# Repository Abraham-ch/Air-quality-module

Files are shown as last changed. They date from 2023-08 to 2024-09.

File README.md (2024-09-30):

# Documentation
## Introduction
To develop a smart city, good air quality is essential, as it is fundamental for the health and well-being of citizens. High levels of air pollution can have negative effects on health, such as respiratory problems, cardiovascular diseases, cancer, and other chronic conditions. The Breath proposal was designed to take measures to reduce air pollution and improve the quality of life for citizens by promoting the use of renewable energy, and encouraging public transportation and sustainable mobility.
## Description
Breath is a project dedicated to air quality monitoring. It consists of an IoT device that contains sensors such as PMS, BME280, and SCD40, capable of measuring humidity, temperature, PM10 and PM2.5 particle concentrations, and various gases that, at high concentrations, could be harmful to humans or cause irritation and respiratory difficulties. The project was developed to be scalable and compact. Due to its low cost, this device can be deployed in various settings, covering crowded places, industrial facilities, and indoor environments. It only requires a power source and WiFi, making it portable if needed. Once deployed, the data will be displayed on an LCD screen or, if required, virtually, showing concentrations through graphs and storing data in the cloud for later use, such as research, monitoring, and forecasting.

## Breath Device
The project's goal is to provide real-time information on air quality. This need arose due to the significant pollution gap in Peru, along with the poor awareness of this issue in Lima.

### Technology Selection
For the project, we will include sensors in addition to a microcontroller and an LCD screen.

<!-- TABLES -->

<table class="tg">
<thead>
  <tr>
    <th class="tg-0pky"></th>
    <th class="tg-9wq8">Module</th>
    <th class="tg-9wq8">Input Voltage</th>
    <th class="tg-9wq8">Output Voltage</th>
  </tr>
</thead>
<tbody>
  <tr>
    <td class="tg-0pky">ESP32 DevKit V1</td>
    <td class="tg-9wq8">Esp32</td>
    <td class="tg-9wq8">5.5 V</td>
    <td class="tg-9wq8">3.3 V</td>
  </tr>
  <tr>
    <td class="tg-0pky">TFT</td>
    <td class="tg-9wq8">TFT 4" LCD<br>SPI screen</td>
    <td class="tg-9wq8">3.3 V</td>
    <td class="tg-9wq8">-</td>
  </tr>
</tbody>
</table>

<table class="tg">
<thead>
  <tr>
    <th class="tg-0pky" colspan="2"></th>
    <th class="tg-9wq8">Sensor</th>
    <th class="tg-9wq8">Measures</th>
    <th class="tg-9wq8">Measurement Range</th>
    <th class="tg-nrix">Error</th>
    <th class="tg-nrix">Voltage Range</th>
  </tr>
</thead>
<tbody>
  <tr>
    <td class="tg-0lax" colspan="2" rowspan="3">SCD40</td>
    <td class="tg-nrix" rowspan="3">SCD40</td>
    <td class="tg-nrix">CO2</td>
    <td class="tg-nrix">[400, 2000] ppm</td>
    <td class="tg-nrix">± 50ppm</td>
    <td class="tg-nrix" rowspan="3">[2.4, 5.5] V</td>
  </tr>
  <tr>
    <td class="tg-nrix">Relative<br>Humidity</td>
    <td class="tg-nrix">[0,100] %RH</td>
    <td class="tg-nrix">± 9% RH</td>
  </tr>
  <tr>
    <td class="tg-nrix">Temperature</td>
    <td class="tg-nrix">[-10, 60]°C</td>
    <td class="tg-nrix">± 1.5°C</td>
  </tr>
  <tr>
    <td class="tg-0lax" colspan="2" rowspan="3">BME280</td>
    <td class="tg-nrix" rowspan="3">BME280</td>
    <td class="tg-nrix">Atmospheric<br>pressure</td>
    <td class="tg-nrix">[300, 1100] hPa</td>
    <td class="tg-nrix">± 5% hPa</td>
    <td class="tg-nrix" rowspan="3">[1.71, 3.6] V</td>
  </tr>
  <tr>
    <td class="tg-9wq8">Relative<br>Humidity</td>
    <td class="tg-9wq8">[0,100] %RH</td>
    <td class="tg-nrix">± 9% RH</td>
  </tr>
  <tr>
    <td class="tg-nrix">Temperature</td>
    <td class="tg-nrix">[-40, 85]°C</td>
    <td class="tg-nrix">± 1.5°C</td>
  </tr>
  <tr>
    <td class="tg-0lax" colspan="2" rowspan="3">PMS5003T</td>
    <td class="tg-nrix" rowspan="3">PMS5003T</td>
    <td class="tg-nrix">PM 1.0</td>
    <td class="tg-nrix">[0, 1000] ug/m3</td>
    <td class="tg-nrix">± 10%ug/m3</td>
    <td class="tg-nrix" rowspan="3">[4.5, 5.5] V</td>
  </tr>
  <tr>
    <td class="tg-9wq8">PM 2.5</td>
    <td class="tg-9wq8">[0, 1000] ug/m3</td>
    <td class="tg-nrix">± 10%ug/m3</td>
  </tr>
  <tr>
    <td class="tg-9wq8">PM 10</td>
    <td class="tg-9wq8">[0, 1000] ug/m3</td>
    <td class="tg-nrix">± 10%ug/m3</td>
  </tr>
</tbody>
</table>

### Configuration and Connections

Schematic of connections between the sensors and modules created in Fritzing.

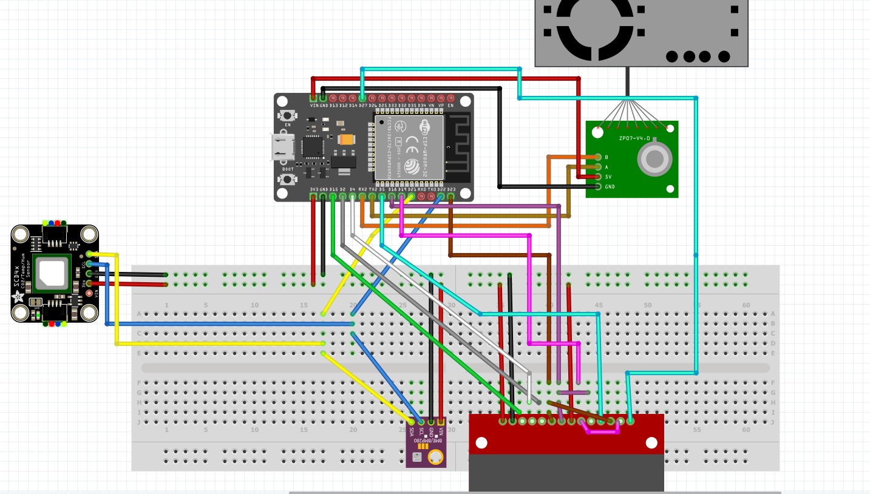
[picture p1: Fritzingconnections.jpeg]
Fritzing Conexiones Fritzing


#### Connections TFT - ESP32
In case we do not want the device screen to be continuously on or want it to be managed routinely, disconnect the LED pin from the 3V3 of the ESP32 and assign a new pin.
We need to keep in mind that from SDO (MISO), the connections are made for the subsequent use of the device's touchscreen panel (which can be omitted).

| 4.0'' TFT 	  | ESP32 	|
|:---:	|:---:	|
| VCC 	| 3V3 	|
| GND 	| GND 	|
| CS 	| D15 	|
| RESET 	| D4 	|
| DC/RS 	| D2 	|
| SDI(MOSI) 	| D23 	|
| SCK 	| D18 	|
| LED 	| 3V3 	|
| SDO(MISO) 	| D19 	|
| T_CLK 	| SCK 	|
| T_CS 	| D5 	|
| T_DIN 	| SDI(MOSI) 	|
| T_DO 	| SDO(MISO) 	|
| T_IRQ 	| D27 	|

#### Connections BME - SCD40 - ESP32
For configuring our device, we need to consider that the module we are using is the ESP32 DEVKIT V1, with only pins 21 and 22 available as SDA and SCL respectively for the I2C communication protocol.

| BME280 	| SCD40 	| ESP32 	|
|:-----:	|:-----:	|:-----:	|
|  GND  	|  GND  	| GND |
|  VCC  	|  VCC  	| 3V3 |
|  SCL  	| SCL  	| 22 |
|  SDA  	| SDA  	| 21 |

Since I2C communication is used for both sensors, they must be connected in parallel to the ESP32. If you need to change a sensor, remember to add its address as will be shown below.  

```c
void setup(void){
  Serial.begin(9600);
  ...
  BME280.begin(0x76); 
  SCD40.begin(0x62);
  ...
}
```

#### Connections PMS5003T - ESP32

If you have an additional 5V power source, it is preferable to connect it instead of the ESP32 power supply.

| PMS5003T 	|  ESP32  	|
|:---:	|:---:	|
| GND 	| GND 	|
| VCC 	| VIN (5V) 	|
| RX 	| TX2 	|
| TX 	| RX2 	|

### Device Requirements:

* Internet connection to communicate with the HiveMQ MQTT platform.
* Power supply through a 5V micro USB connection.
* Not water-resistant and should not be submerged.

### Communication:

The HiveMQ MQTT platform will be used as the broker for device communications.

### Deployment
Once the connections are made, the project involves assembling the device and writing the code. Below is a sample of the raw product.

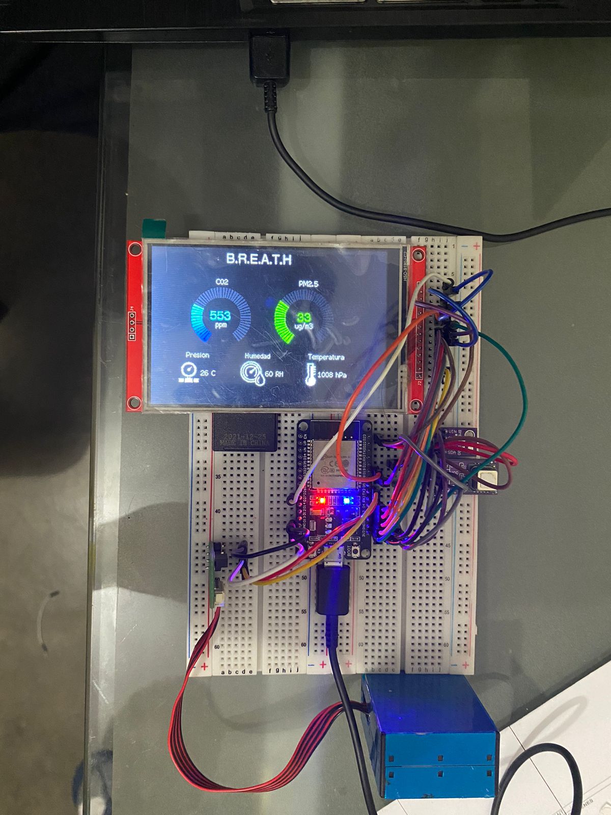
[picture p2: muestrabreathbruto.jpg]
Breath breadboard example Breadboard example


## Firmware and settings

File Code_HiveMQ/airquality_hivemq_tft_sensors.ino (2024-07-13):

#include "iconotemperatura.h"
#include "iconopresion.h"
#include "iconohumedad.h"
#include <TFT_eSPI.h> 
#include <Wire.h>
#include <Adafruit_Sensor.h>
#include <Adafruit_BME280.h>
#include "SparkFun_SCD4x_Arduino_Library.h" 
#include <WiFi.h>  
#include <PubSubClient.h>
#include <WiFiClientSecure.h>
#include <SPI.h>
#include <stdio.h>
#include <time.h>

int o = 0;

char dtime[100];
char dpm25[100];
char dco2[100];
char dpressure[100]; //pressure
char dtemperature[100]; //temperature
char dhumidity[100]; //humidity

#define RXD2 16 // To sensor TXD
#define TXD2 17 // To sensor RXD

#define RED2RED 0
#define GREEN2GREEN 1
#define BLUE2BLUE 2
#define BLUE2RED 3
#define GREEN2RED 4
#define RED2GREEN 5
 
#define TFT_GREY 0x2104 // Dark grey 16 bit colour

SCD4x mySensor;
Adafruit_BME280 bme1;

//---- WiFi settings
const char* ssid = "*******"; // Put your WiFi SSID here 
const char* password = "*******";  // Put your WiFi password here
//---- MQTT Broker settings
const char* mqtt_server = "*************.hivemq.cloud"; // replace with your broker url
// replace with your Credentials
const char* mqtt_username = "******"; 
const char* mqtt_password = "******";
const int mqtt_port = 8883; // MQTT port usually is 8883 for HiveMQ
const long  gmtOffset_sec = -18000;
const int   daylightOffset_sec = 0;

//===========================
WiFiClientSecure espClient;  
PubSubClient client(espClient);
unsigned long lastMsg = 0;
#define MSG_BUFFER_SIZE  (50)
char msg[MSG_BUFFER_SIZE];
//============= Configure OUTPUT Here============================

const char* AirQuality0_topic= "AirQuality/humidity";
const char* AirQuality1_topic= "AirQuality/temperature";
const char* AirQuality2_topic= "AirQuality/pressure";
const char* AirQuality3_topic= "AirQuality/co2";
const char* AirQuality4_topic= "AirQuality/pm25";
const char* AirQuality5_topic= "AirQuality/date";

//============= Config Command Here==============================
//const char* command1_topic="command1";
//const char* command1_topic="command2";

static const char *root_ca PROGMEM = R"EOF(
-----BEGIN CERTIFICATE-----
MIIFazCCA1OgAwIBAgIRAIIQz7DSQONZRGPgu2OCiwAwDQYJKoZIhvcNAQELBQAw
TzELMAkGA1UEBhMCVVMxKTAnBgNVBAoTIEludGVybmV0IFNlY3VyaXR5IFJlc2Vh
cmNoIEdyb3VwMRUwEwYDVQQDEwxJU1JHIFJvb3QgWDEwHhcNMTUwNjA0MTEwNDM4
WhcNMzUwNjA0MTEwNDM4WjBPMQswCQYDVQQGEwJVUzEpMCcGA1UEChMgSW50ZXJu
ZXQgU2VjdXJpdHkgUmVzZWFyY2ggR3JvdXAxFTATBgNVBAMTDElTUkcgUm9vdCBY
MTCCAiIwDQYJKoZIhvcNAQEBBQADggIPADCCAgoCggIBAK3oJHP0FDfzm54rVygc
h77ct984kIxuPOZXoHj3dcKi/vVqbvYATyjb3miGbESTtrFj/RQSa78f0uoxmyF+
0TM8ukj13Xnfs7j/EvEhmkvBioZxaUpmZmyPfjxwv60pIgbz5MDmgK7iS4+3mX6U
A5/TR5d8mUgjU+g4rk8Kb4Mu0UlXjIB0ttov0DiNewNwIRt18jA8+o+u3dpjq+sW
T8KOEUt+zwvo/7V3LvSye0rgTBIlDHCNAymg4VMk7BPZ7hm/ELNKjD+Jo2FR3qyH
B5T0Y3HsLuJvW5iB4YlcNHlsdu87kGJ55tukmi8mxdAQ4Q7e2RCOFvu396j3x+UC
B5iPNgiV5+I3lg02dZ77DnKxHZu8A/lJBdiB3QW0KtZB6awBdpUKD9jf1b0SHzUv
KBds0pjBqAlkd25HN7rOrFleaJ1/ctaJxQZBKT5ZPt0m9STJEadao0xAH0ahmbWn
OlFuhjuefXKnEgV4We0+UXgVCwOPjdAvBbI+e0ocS3MFEvzG6uBQE3xDk3SzynTn
jh8BCNAw1FtxNrQHusEwMFxIt4I7mKZ9YIqioymCzLq9gwQbooMDQaHWBfEbwrbw
qHyGO0aoSCqI3Haadr8faqU9GY/rOPNk3sgrDQoo//fb4hVC1CLQJ13hef4Y53CI
rU7m2Ys6xt0nUW7/vGT1M0NPAgMBAAGjQjBAMA4GA1UdDwEB/wQEAwIBBjAPBgNV
HRMBAf8EBTADAQH/MB0GA1UdDgQWBBR5tFnme7bl5AFzgAiIyBpY9umbbjANBgkq
hkiG9w0BAQsFAAOCAgEAVR9YqbyyqFDQDLHYGmkgJykIrGF1XIpu+ILlaS/V9lZL
ubhzEFnTIZd+50xx+7LSYK05qAvqFyFWhfFQDlnrzuBZ6brJFe+GnY+EgPbk6ZGQ
3BebYhtF8GaV0nxvwuo77x/Py9auJ/GpsMiu/X1+mvoiBOv/2X/qkSsisRcOj/KK
NFtY2PwByVS5uCbMiogziUwthDyC3+6WVwW6LLv3xLfHTjuCvjHIInNzktHCgKQ5
ORAzI4JMPJ+GslWYHb4phowim57iaztXOoJwTdwJx4nLCgdNbOhdjsnvzqvHu7Ur
TkXWStAmzOVyyghqpZXjFaH3pO3JLF+l+/+sKAIuvtd7u+Nxe5AW0wdeRlN8NwdC
jNPElpzVmbUq4JUagEiuTDkHzsxHpFKVK7q4+63SM1N95R1NbdWhscdCb+ZAJzVc
oyi3B43njTOQ5yOf+1CceWxG1bQVs5ZufpsMljq4Ui0/1lvh+wjChP4kqKOJ2qxq
4RgqsahDYVvTH9w7jXbyLeiNdd8XM2w9U/t7y0Ff/9yi0GE44Za4rF2LN9d11TPA
mRGunUHBcnWEvgJBQl9nJEiU0Zsnvgc/ubhPgXRR4Xq37Z0j4r7g1SgEEzwxA57d
emyPxgcYxn/eR44/KJ4EBs+lVDR3veyJm+kXQ99b21/+jh5Xos1AnX5iItreGCc=
-----END CERTIFICATE-----
)EOF";

String topic;
String messageTemp;
String message;

void callback(char* topic, byte* payload, unsigned int length) {
  String incommingMessage = "";
  for (int i = 0; i < length; i++) incommingMessage+=(char)payload[i];
  Serial.println("Message arrived ["+String(topic)+"]"+incommingMessage);
  messageTemp = topic;
  Serial.print(messageTemp);
  //==============MESSAGE RECEPTION HERE (Uncomment to edit)====================
  /* if (messageTemp == "MESSAGE INPUT"){
    YOUR VARIABLE = incommingMessage.to**WHAT YOU NEED**();
  }*/

}
void reconnect() {
  // Loop until we're reconnected
  while (!client.connected()) {
    Serial.print("Attempting MQTT connection...");
    String clientId = "ESP8266Client-";   // Create a random client ID
    clientId += String(random(0xffff), HEX);
    // Attempt to connect
    if (client.connect(clientId.c_str(), mqtt_username, mqtt_password)) {
      Serial.println("connected");

      //SUBSCRIBE TO TOPIC HERE

     client.subscribe("SUBSCRIBE NAME");

    } else {
      Serial.print("failed, rc=");
      Serial.print(client.state());
      Serial.println(" try again in 5 seconds");   // Wait 5 seconds before retrying
      delay(5000);
    }
  }
}
//============================================ADD USER VARIABLE HERE====================================


TFT_eSPI tft = TFT_eSPI(); // Invoke custom library with default width and height

int CO2lecture = 0;
int pm25lecture = 0;

int reading = 0; // Value to be displayed
int d = 0;       // Variable used for the sinewave test waveform
boolean range_error = 0;
int8_t ramp = 1;
 
void setup(void)
{
  Serial.begin(9600);
  Serial.print("\nConnecting to ");
  Serial.println(ssid);
  WiFi.mode(WIFI_STA);
  WiFi.begin(ssid, password);
  client.setCallback(callback);
  while (WiFi.status() != WL_CONNECTED) {
    delay(500);
    Serial.print(".");
  }
  randomSeed(micros());
  Serial.println("\nWiFi connected\nIP address: ");
  Serial.println(WiFi.localIP());
  while (!Serial) delay(1);
  espClient.setCACert(root_ca);
  client.setServer(mqtt_server, mqtt_port);
  client.setCallback(callback);
  delay(1000);
  configTime(0, 0, "pool.ntp.org");
  while (!time(nullptr)) {
    Serial.print(".");
  delay(1000);
  }
 
  Serial1.begin(9600, SERIAL_8N1, RXD2, TXD2);
  Wire.begin(SDA, SCL,100000);
  bme1.begin(0x76); 
  mySensor.begin(0x62);

  tft.begin();
  tft.setRotation(1);
  tft.fillScreen(TFT_BLACK);
 
  tft.setTextColor(TFT_WHITE, TFT_BLACK);
  tft.drawString("Breath", 200, 10, 4);
  //tft.drawString("Weather", 350, 10, 2);
 
  tft.drawString("CO2", 130, 60, 2);
  tft.drawString("PM2.5", 300, 60, 2);

  tft.drawString("Temperatura", 65, 210, 2);
  tft.drawString("Humedad", 190, 210, 2);
  tft.drawString("Presion", 320, 210, 2);
  tft.pushImage(50,230,50,50,iconotemperatura);
  tft.pushImage(180,230,50,50,iconohumedad);
  tft.pushImage(300,230,50,50,iconopresion);

  delay(5000);
}

struct pms5003data {
  uint16_t framelen;
  uint16_t pm10_standard, pm25_standard, pm100_standard;
  uint16_t pm10_env, pm25_env, pm100_env;
  uint16_t particles_03um, particles_05um, particles_10um, particles_25um, particles_50um, particles_100um;
  uint16_t unused;
  uint16_t checksum;
};

struct pms5003data data;

void loop()
{
  //============== NO TOUCHY=======================
  if (!client.connected()) reconnect();
     client.loop();
  //============== ADD LOOP CODE HERE==============

  int co2, tscd40, tbme280, hscd40, hbme280, pbme280, pm25um= 0;   
  readPMSdata(&Serial1);
  mySensor.readMeasurement(); 
  
  pm25um = data.pm25_standard;

  co2 = mySensor.getCO2();
  tscd40 = mySensor.getTemperature();
  tbme280 = bme1.readTemperature();
  hscd40 = mySensor.getHumidity();
  hbme280 = bme1.readHumidity();
  pbme280 = bme1.readPressure() / 100.0F;

  Serial.println();
  Serial.print("CO2(ppm):");
  Serial.print(co2);
  Serial.print("\tPM 2.5:");
  Serial.print(pm25um);

  Serial.print("\tT1:");
  Serial.print(tbme280);  
  Serial.print("\tT2:");
  Serial.print(tscd40);  

  Serial.print("\tRH1:");
  Serial.print(hbme280);
  Serial.print("\tRH2:");
  Serial.print(hscd40);

  Serial.print("\tP(hPa):");
  Serial.print(pbme280);

  char buffer1[20];
  char buffer2[20];
  char buffer3[20];

  sprintf(buffer1, "%i °C", tbme280);
  sprintf(buffer2, "%i %RH", hbme280);
  sprintf(buffer3, "%i hPa", pbme280);
  o = o + 1;
  if (o>1){
    tft.drawString(buffer1, 120, 255, 2);
    tft.drawString(buffer2, 255, 255, 2);
    tft.drawString(buffer3, 380, 255, 2);
  }
  CO2lecture = (int)co2;
  pm25lecture = (int)pm25um;

  // Test with a slowly changing value from a Sine function
  d += 4;
  if (d >= 360)
    d = 0;

  // Set the the position, gap between meters, and inner radius of the meters
  int xpos = 0, ypos = 5, gap = 4, radius = 40;

  xpos = 80, ypos = 80, gap = 50, radius = 60;

  //reading = 800 + 150 * sineWave(d + 90);
  xpos = gap + ringMeter(CO2lecture, 0, 2000, xpos, ypos, radius, "ppm", BLUE2RED); // Draw analogue meter

  //reading = 15 + 15 * sineWave(d + 150);
  xpos = gap + ringMeter(pm25lecture, 0, 100, xpos, ypos, radius, "ug/m3", GREEN2GREEN); // Draw analogue meter

  time_t now;
  struct tm timeinfo;
  char strftime_buf[64];

  time(&now);
  localtime_r(&now, &timeinfo);
  strftime(strftime_buf, sizeof(strftime_buf), "%Y-%m-%dT%H:%M:%S", &timeinfo);
  
  sprintf(dhumidity,"8e234a60-4b52-431a-8c33-98fac1bca3a9/1/1/%i/%s",hbme280,strftime_buf);
  sprintf(dtemperature,"8e234a60-4b52-431a-8c33-98fac1bca3a9/1/1/%i/%s",tbme280,strftime_buf);
  sprintf(dpressure,"8e234a60-4b52-431a-8c33-98fac1bca3a9/1/1/%i/%s",pbme280,strftime_buf);
  sprintf(dco2,"8e234a60-4b52-431a-8c33-98fac1bca3a9/1/1/%i/%s",co2,strftime_buf);
  sprintf(dpm25,"8e234a60-4b52-431a-8c33-98fac1bca3a9/1/1/%i/%s",pm25um,strftime_buf);
  sprintf(dtime,"8e234a60-4b52-431a-8c33-98fac1bca3a9/1/1/%s",strftime_buf);

  delay(5000);

  publishMessage(AirQuality0_topic, dhumidity,true);
  publishMessage(AirQuality1_topic, dtemperature,true);
  publishMessage(AirQuality2_topic, dpressure,true);
  publishMessage(AirQuality3_topic, dco2,true);
  publishMessage(AirQuality4_topic, dpm25,true);
  publishMessage(AirQuality5_topic, dtime,true);

  delay(5000);
}
 
// #########################################################################
//  Draw the meter on the screen, returns x coord of righthand side
// #########################################################################
int ringMeter(int value, int vmin, int vmax, int x, int y, int r, const char *units, byte scheme)
{
  // Minimum value of r is about 52 before value text intrudes on ring
  // drawing the text first is an option
 
  x += r;
  y += r; // Calculate coords of centre of ring
 
  int w = r / 3; // Width of outer ring is 1/4 of radius
 
  int angle = 150; // Half the sweep angle of meter (300 degrees)
 
  int v = map(value, vmin, vmax, -angle, angle); // Map the value to an angle v
 
  byte seg = 3; // Segments are 3 degrees wide = 100 segments for 300 degrees
  byte inc = 6; // Draw segments every 3 degrees, increase to 6 for segmented ring
 
  // Variable to save "value" text colour from scheme and set default
  int colour = TFT_BLUE;
 
  // Draw colour blocks every inc degrees
  for (int i = -angle + inc / 2; i < angle - inc / 2; i += inc)
  {
    // Calculate pair of coordinates for segment start
    float sx = cos((i - 90) * 0.0174532925);
    float sy = sin((i - 90) * 0.0174532925);
    uint16_t x0 = sx * (r - w) + x;
    uint16_t y0 = sy * (r - w) + y;
    uint16_t x1 = sx * r + x;
    uint16_t y1 = sy * r + y;
 
    // Calculate pair of coordinates for segment end
    float sx2 = cos((i + seg - 90) * 0.0174532925);
    float sy2 = sin((i + seg - 90) * 0.0174532925);
    int x2 = sx2 * (r - w) + x;
    int y2 = sy2 * (r - w) + y;
    int x3 = sx2 * r + x;
    int y3 = sy2 * r + y;
 
    if (i < v)
    { // Fill in coloured segments with 2 triangles
      switch (scheme)
      {
      case 0:
        colour = TFT_RED;
        break; // Fixed colour
      case 1:
        colour = TFT_GREEN;
        break; // Fixed colour
      case 2:
        colour = TFT_BLUE;
        break; // Fixed colour
      case 3:
        colour = rainbow(map(i, -angle, angle, 0, 127));
        break; // Full spectrum blue to red
      case 4:
        colour = rainbow(map(i, -angle, angle, 70, 127));
        break; // Green to red (high temperature etc)
      case 5:
        colour = rainbow(map(i, -angle, angle, 127, 63));
        break; // Red to green (low battery etc)
      default:
        colour = TFT_BLUE;
        break; // Fixed colour
      }
      tft.fillTriangle(x0, y0, x1, y1, x2, y2, colour);
      tft.fillTriangle(x1, y1, x2, y2, x3, y3, colour);
      //text_colour = colour; // Save the last colour drawn
    }
    else // Fill in blank segments
    {
      tft.fillTriangle(x0, y0, x1, y1, x2, y2, TFT_GREY);
      tft.fillTriangle(x1, y1, x2, y2, x3, y3, TFT_GREY);
    }
  }
  // Convert value to a string
  char buf[10];
  byte len = 3;
  if (value > 999)
    len = 5;+
  dtostrf(value, len, 0, buf);
  buf[len] = ' ';
  buf[len + 1] = 0; // Add blanking space and terminator, helps to centre text too!
  // Set the text colour to default
  tft.setTextSize(1);
 
  tft.setTextColor(TFT_WHITE, TFT_BLACK);
  // Uncomment next line to set the text colour to the last segment value!
  tft.setTextColor(colour, TFT_BLACK);
  tft.setTextDatum(MC_DATUM);
  // Print value, if the meter is large then use big font 8, othewise use 4
  if (r > 84)
  {
    tft.setTextPadding(55 * 3);   // Allow for 3 digits each 55 pixels wide
    tft.drawString(buf, x, y, 8); // Value in middle
  }
  else
  {
    tft.setTextPadding(3 * 14);   // Allow for 3 digits each 14 pixels wide
    tft.drawString(buf, x, y, 4); // Value in middle
  }
  tft.setTextSize(1);
  tft.setTextPadding(0);
  // Print units, if the meter is large then use big font 4, othewise use 2
  tft.setTextColor(TFT_WHITE, TFT_BLACK);
  if (r > 84)
    tft.drawString(units, x, y + 60, 4); // Units display
  else
    tft.drawString(units, x, y + 15, 2); // Units display
 
  // Calculate and return right hand side x coordinate
  return x + r;
}
 

unsigned int rainbow(byte value)
{
  // Value is expected to be in range 0-127
  // The value is converted to a spectrum colour from 0 = blue through to 127 = red
 
  byte red = 0;   // Red is the top 5 bits of a 16 bit colour value
  byte green = 0; // Green is the middle 6 bits
  byte blue = 0;  // Blue is the bottom 5 bits
 
  byte quadrant = value / 32;
 
  if (quadrant == 0)
  {
    blue = 31;
    green = 2 * (value % 32);
    red = 0;
  }
  if (quadrant == 1)
  {
    blue = 31 - (value % 32);
    green = 63;
    red = 0;
  }
  if (quadrant == 2)
  {
    blue = 0;
    green = 63;
    red = value % 32;
  }
  if (quadrant == 3)
  {
    blue = 0;
    green = 63 - 2 * (value % 32);
    red = 31;
  }
  return (red << 11) + (green << 5) + blue;
}
 
// #########################################################################
// Return a value in range -1 to +1 for a given phase angle in degrees
// #########################################################################
float sineWave(int phase)
{
  return sin(phase * 0.0174532925);
}
 
//====================================================================================
// This is the function to draw the icon stored as an array in program memory (FLASH)
//====================================================================================
 
// To speed up rendering we use a 64 pixel buffer
#define BUFF_SIZE 64
 
// Draw array "icon" of defined width and height at coordinate x,y
// Maximum icon size is 255x255 pixels to avoid integer overflow
 
void drawIcon(const unsigned short *icon, int16_t x, int16_t y, int8_t width, int8_t height)
{
 
  uint16_t pix_buffer[BUFF_SIZE]; // Pixel buffer (16 bits per pixel)
 
  tft.startWrite();
 
  // Set up a window the right size to stream pixels into
  tft.setAddrWindow(x, y, width, height);
 
  // Work out the number whole buffers to send
  uint16_t nb = ((uint16_t)height * width) / BUFF_SIZE;
 
  // Fill and send "nb" buffers to TFT
  for (int i = 0; i < nb; i++)
  {
    for (int j = 0; j < BUFF_SIZE; j++)
    {
      pix_buffer[j] = pgm_read_word(&icon[i * BUFF_SIZE + j]);
    }
    tft.pushColors(pix_buffer, BUFF_SIZE);
  }
 
  // Work out number of pixels not yet sent
  uint16_t np = ((uint16_t)height * width) % BUFF_SIZE;
 
  // Send any partial buffer left over
  if (np)
  {
    for (int i = 0; i < np; i++)
      pix_buffer[i] = pgm_read_word(&icon[nb * BUFF_SIZE + i]);
    tft.pushColors(pix_buffer, np);
  }
 
  tft.endWrite();
}

// PMSSSSSSS
boolean readPMSdata(Stream *s) {
  if (! s->available()) {
    return false;
  }

  // Read a byte at a time until we get to the special '0x42' start-byte
  if (s->peek() != 0x42) {
    s->read();
    return false;
  }

  // Now read all 32 bytes
  if (s->available() < 32) {
    return false;
  }

  uint8_t buffer[32];
  uint16_t sum = 0;
  s->readBytes(buffer, 32);

  // get checksum ready
  for (uint8_t i = 0; i < 30; i++) {
    sum += buffer[i];
  }

  /* debugging
    for (uint8_t i=2; i<32; i++) {
    Serial.print("0x"); Serial.print(buffer[i], HEX); Serial.print(", ");
    }
    Serial.println();
  */

  // The data comes in endian'd, this solves it so it works on all platforms
  uint16_t buffer_u16[15];
  for (uint8_t i = 0; i < 15; i++) {
    buffer_u16[i] = buffer[2 + i * 2 + 1];
    buffer_u16[i] += (buffer[2 + i * 2] << 8);
  }

  // put it into a nice struct :)
  memcpy((void *)&data, (void *)buffer_u16, 30);

  if (sum != data.checksum) {
    Serial.println("Checksum failure");
    return false;
  }
  // success!
  return true;
}

//======================================= publising as string
void publishMessage(const char* topic, String payload , boolean retained){
  if (client.publish(topic, payload.c_str(), true))
      Serial.println("Message publised ["+String(topic)+"]: "+payload);
}
